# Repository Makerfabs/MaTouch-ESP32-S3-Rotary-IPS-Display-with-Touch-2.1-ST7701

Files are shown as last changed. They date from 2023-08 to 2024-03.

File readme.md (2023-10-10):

MaTouch ESP32-S3 Rotary IPS Display with Touch 2.1 ST7701

```c++
/*
Version:		V1.0
Author:		Vincent
Create Date:	2023/8/24
Note:

    2023/8/29   V1.1    Change out factory test program

*/
```

# Makerfabs

[Makerfabs home page](https://www.makerfabs.com/)

[Makerfabs Wiki](https://wiki.makerfabs.com/)

## Intruduce

Product Link:[]()

Wiki Link : []()

## Features

Specs:
- Controller: ESP32-S3
- Wireless: WiFi& Bluetooth 5.0
- Touch Panel Driver: CST826
- USB: USB Native, Type-C
- Power Supply: USB Type-C 5.0V(4.0V~5.25V)
- Button: Flash button and reset button
- Arduino support: Yes
- MicroPython support: Yes
- Operation temperature: -40℃ to +85℃

# Usage

## Libraries

Related library versions

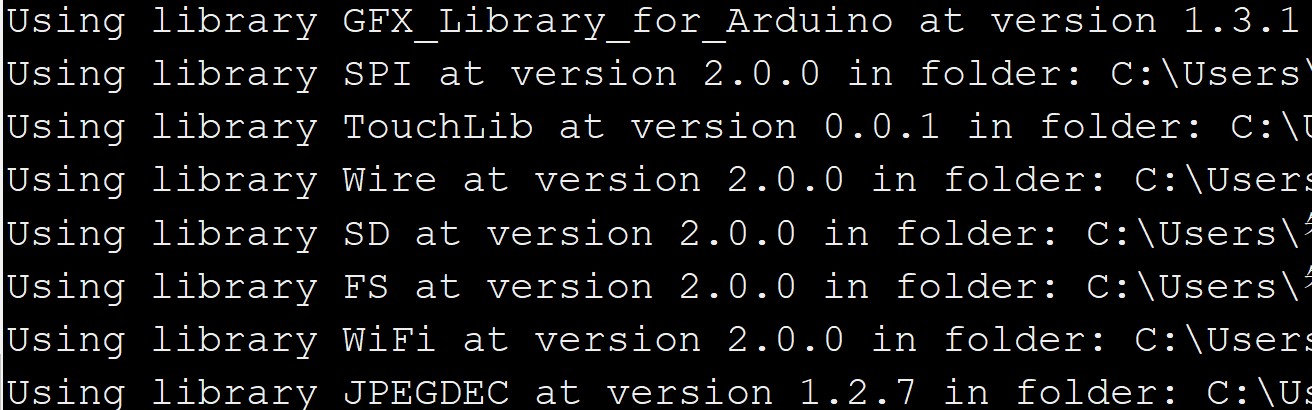
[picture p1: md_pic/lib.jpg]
library


- Use type-c use cable connect USB-TTL to PC.
- Select "ESP32-S3 DEV Module"
- Select PSRAM "OPI PSRAM"

"mf_Lvgl" library is modified from Lvgl library (version 8.3.2). 

Please unzip "lib/mf_Lvgl.zip","TouchLib" and copy to arduino library directory.

## Example

### fw_test

Old factory test program.
Test screen display and touch, as well as ring encoders and press switches.

### fw_test_v2

Factory test program.
Test screen display and touch, as well as ring encoders and press switches. After press screen, it will change different screen.

### fs_test

No SD card is required, files are stored in SPIFFS in Flash, and the display is switched by rotary encoder.

Need use arduino-esp32fs-plugin upload picture. And install JPEGDEC version 1.2.8

[arduino-esp32fs-plugin](https://github.com/me-no-dev/arduino-esp32fs-plugin)

### stepper_control

Control stepper motor rotation speed, rotation direction.

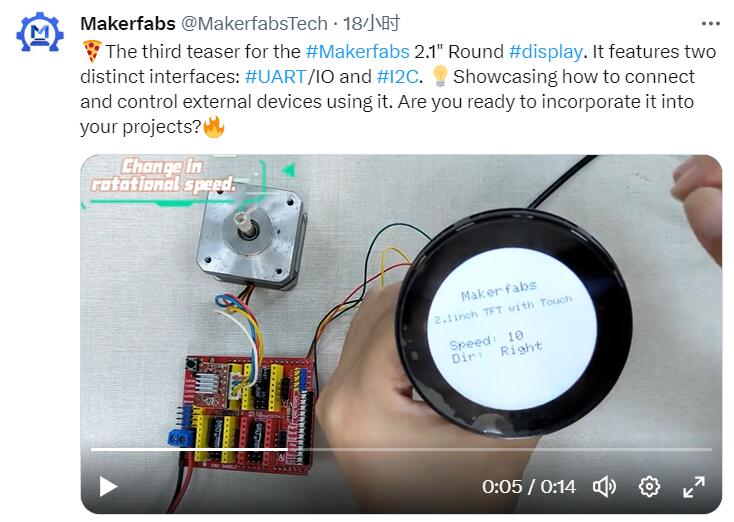
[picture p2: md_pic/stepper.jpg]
stepper


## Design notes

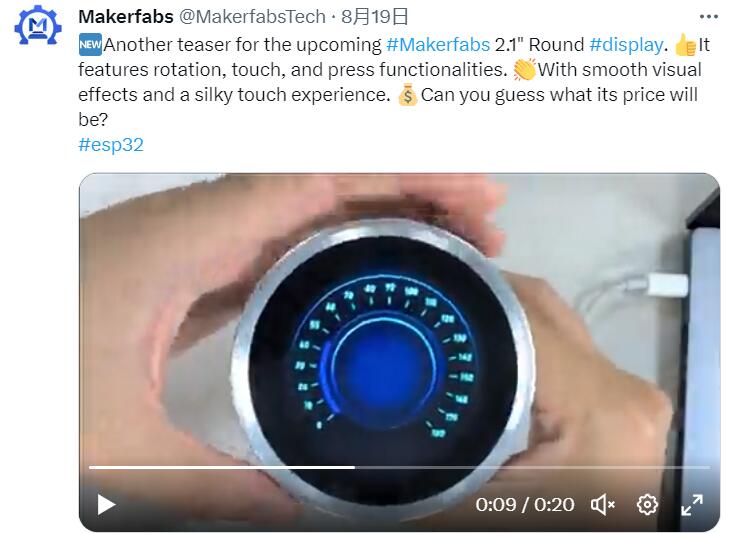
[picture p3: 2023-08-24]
md_pic/lvgl.jpg

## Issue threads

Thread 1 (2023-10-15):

No more compatible with GFX lib Version: 1.3.8, 1.3.7, 1.3.6, 1.3.5, 1.3.4, 1.3.3, 1.3.2.

Uspizig, 2023-10-15:
Compilation crashes on this one in the example with the GFX lib versions  1.3.8, 1.3.7, 1.3.6, 1.3.5, 1.3.4, 1.3.3, 1.3.2.
Works on 1.3.1. Please make it availible as well on newer GFX lib versions

Arduino_ESP32RGBPanel *bus = new Arduino_ESP32RGBPanel(
    1 /* CS */, 46 /* SCK */, 0 /* SDA */,
    2 /* DE */, 42 /* VSYNC */, 3 /* HSYNC */, 45 /* PCLK */,
    11 /* R0 */, 15 /* R1 */, 12 /* R2 */, 16 /* R3 */, 21 /* R4 */,
    39 /* G0/P22 */, 7 /* G1/P23 */, 47 /* G2/P24 */, 8 /* G3/P25 */, 48 /* G4/P26 */, 9 /* G5 */,
    4 /* B0 */, 41 /* B1 */, 5 /* B2 */, 40 /* B3 */, 6 /* B4 */
);

C:\Users\User\Downloads\MaTouch-ESP32-S3-Rotary-IPS-Display-with-Touch-2.1-ST7701-main\MaTouch-ESP32-S3-Rotary-IPS-Display-with-Touch-2.1-ST7701-main\example\fs_test\fs_test.ino:33:1: error: no matching function for call to 'Arduino_ESP32RGBPanel::Arduino_ESP32RGBPanel(int, int, int, int, int, int, int, int, int, int, int, int, int, int, int, int, int, int, int, int, int, int, int)'
 );
 ^
In file included from c:\Users\User\Documents\Arduino\libraries\GFX_Library_for_Arduino\src/Arduino_GFX_Library.h:15,
                 from C:\Users\User\Downloads\MaTouch-ESP32-S3-Rotary-IPS-Display-with-Touch-2.1-ST7701-main\MaTouch-ESP32-S3-Rotary-IPS-Display-with-Touch-2.1-ST7701-main\example\fs_test\fs_test.ino:1:
c:\Users\User\Documents\Arduino\libraries\GFX_Library_for_Arduino\src/databus/Arduino_ESP32RGBPanel.h:59:3: note: candidate: 'Arduino_ESP32RGBPanel::Arduino_ESP32RGBPanel(int8_t, int8_t, int8_t, int8_t, int8_t, int8_t, int8_t, int8_t, int8_t, int8_t, int8_t, int8_t, int8_t, int8_t, int8_t, int8_t, int8_t, int8_t, int8_t, int8_t, uint16_t, uint16_t, uint16_t, uint16_t, uint16_t, uint16_t, uint16_t, uint16_t, uint16_t, int32_t, bool, uint16_t, uint16_t)'
   Arduino_ESP32RGBPanel(
   ^~~~~~~~~~~~~~~~~~~~~
c:\Users\User\Documents\Arduino\libraries\GFX_Library_for_Arduino\src/databus/Arduino_ESP32RGBPanel.h:59:3: note:   candidate expects 33 arguments, 23 provided
c:\Users\User\Documents\Arduino\libraries\GFX_Library_for_Arduino\src/databus/Arduino_ESP32RGBPanel.h:56:7: note: candidate: 'constexpr Arduino_ESP32RGBPanel::Arduino_ESP32RGBPanel(const Arduino_ESP32RGBPanel&)'
 class Arduino_ESP32RGBPanel
       ^~~~~~~~~~~~~~~~~~~~~
c:\Users\User\Documents\Arduino\libraries\GFX_Library_for_Arduino\src/databus/Arduino_ESP32RGBPanel.h:56:7: note:   candidate expects 1 argument, 23 provided
c:\Users\User\Documents\Arduino\libraries\GFX_Library_for_Arduino\src/databus/Arduino_ESP32RGBPanel.h:56:7: note: candidate: 'constexpr Arduino_ESP32RGBPanel::Arduino_ESP32RGBPanel(Arduino_ESP32RGBPanel&&)'
c:\Users\User\Documents\Arduino\libraries\GFX_Library_for_Arduino\src/databus/Arduino_ESP32RGBPanel.h:56:7: note:   candidate expects 1 argument, 23 provided
C:\Users\User\Downloads\MaTouch-ESP32-S3-Rotary-IPS-Display-with-Touch-2.1-ST7701-main\MaTouch-ESP32-S3-Rotary-IPS-Display-with-Touch-2.1-ST7701-main\example\fs_test\fs_test.ino:36:1: error: 'Arduino_ST7701_RGBPanel' does not name a type; did you mean 'Arduino_ESP32RGBPanel'?
 Arduino_ST7701_RGBPanel *gfx = new Arduino_ST7701_RGBPanel(
 ^~~~~~~~~~~~~~~~~~~~~~~
 Arduino_ESP32RGBPanel
C:\Users\User\Downloads\MaTouch-ESP32-S3-Rotary-IPS-Display-with-Touch-2.1-ST7701-main\MaTouch-ESP32-S3-Rotary-IPS-Display-with-Touch-2.1-ST7701-main\example\fs_test\fs_test.ino: In function 'int jpegDrawCallback(JPEGDRAW*)':
C:\Users\User\Downloads\MaTouch-ESP32-S3-Rotary-IPS-Display-with-Touch-2.1-ST7701-main\MaTouch-ESP32-S3-Rotary-IPS-Display-with-Touch-2.1-ST7701-main\example\fs_test\fs_test.ino:50:5: error: 'gfx' was not declared in this scope
     gfx->draw16bitBeRGBBitmap(pDraw->x, pDraw->y, pDraw->pPixels, pDraw->iWidth, pDraw->iHeight);
     ^~~
C:\Users\User\Downloads\MaTouch-ESP32-S3-Rotary-IPS-Display-with-Touch-2.1-ST7701-main\MaTouch-ESP32-S3-Rotary-IPS-Display-with-Touch-2.1-ST7701-main\example\fs_test\fs_test.ino: In function 'void setup()':
C:\Users\User\Downloads\MaTouch-ESP32-S3-Rotary-IPS-Display-with-Touch-2.1-ST7701-main\MaTouch-ESP32-S3-Rotary-IPS-Display-with-Touch-2.1-ST7701-main\example\fs_test\fs_test.ino:60:5: error: 'gfx' was not declared in this scope
     gfx->begin();
     ^~~

exit status 1

Compilation error: no matching function for call to 'Arduino_ESP32RGBPanel::Arduino_ESP32RGBPanel(int, int, int, int, int, int, int, int, int, int, int, int, int, int, int, int, int, int, int, int, int, int, int)'

only works with GFX lib 1.3.1

Uspizig, 2023-10-16:
This might be a workaround. [Untested due to lack of Hardware]
At least it compiles:

#define I2C_SDA_PIN 17
#define I2C_SCL_PIN 18
#define DISPLAY_DC GFX_NOT_DEFINED
#define DISPLAY_CS 1
#define DISPLAY_SCK 46
#define DISPLAY_MOSI 0
#define DISPLAY_MISO GFX_NOT_DEFINED

#define DISPLAY_DE 2
#define DISPLAY_VSYNC 42
#define DISPLAY_HSYNC 3
#define DISPLAY_PCLK 45
#define DISPLAY_R0 11
#define DISPLAY_R1 15
#define DISPLAY_R2 12
#define DISPLAY_R3 16
#define DISPLAY_R4 21
#define DISPLAY_G0 39
#define DISPLAY_G1 7
#define DISPLAY_G2 47
#define DISPLAY_G3 8
#define DISPLAY_G4 48
#define DISPLAY_G5 9
#define DISPLAY_B0 4
#define DISPLAY_B1 41
#define DISPLAY_B2 5
#define DISPLAY_B3 40
#define DISPLAY_B4 6
#define DISPLAY_HSYNC_POL 1
#define DISPLAY_VSYNC_POL 1
#define DISPLAY_HSYNC_FRONT_PORCH 10
#define DISPLAY_VSYNC_FRONT_PORCH 10
#define DISPLAY_HSYNC_BACK_PORCH 50
#define DISPLAY_VSYNC_BACK_PORCH 20
#define DISPLAY_HSYNC_PULSE_WIDTH 8
#define DISPLAY_VSYNC_PULSE_WIDTH 8

Arduino_DataBus *bus = new Arduino_SWSPI(
    DISPLAY_DC /* DC */, DISPLAY_CS /* CS */,
    DISPLAY_SCK /* SCK */, DISPLAY_MOSI /* MOSI */, DISPLAY_MISO /* MISO */);

Arduino_ESP32RGBPanel *rgbpanel = new Arduino_ESP32RGBPanel(
    DISPLAY_DE, DISPLAY_VSYNC , DISPLAY_HSYNC, DISPLAY_PCLK,
    DISPLAY_R0, DISPLAY_R1, DISPLAY_R2, DISPLAY_R3, DISPLAY_R4,
    DISPLAY_G0, DISPLAY_G1, DISPLAY_G2, DISPLAY_G3, DISPLAY_G4, DISPLAY_G5,
    DISPLAY_B0, DISPLAY_B1, DISPLAY_B2, DISPLAY_B3, DISPLAY_B4,
    DISPLAY_HSYNC_POL, DISPLAY_HSYNC_FRONT_PORCH, DISPLAY_HSYNC_PULSE_WIDTH, DISPLAY_VSYNC_BACK_PORCH,
    DISPLAY_VSYNC_POL, DISPLAY_VSYNC_FRONT_PORCH, DISPLAY_VSYNC_PULSE_WIDTH, DISPLAY_VSYNC_BACK_PORCH);

Arduino_RGB_Display *gfx = new Arduino_RGB_Display(
    480 /* width */, 480 /* height */, rgbpanel, 0 /* rotation */, true /* auto_flush */,
    bus, GFX_NOT_DEFINED /* RST */, st7701_type5_init_operations, sizeof(st7701_type5_init_operations));

//Arduino_ESP32RGBPanel *bus = new Arduino_ESP32RGBPanel(
//    1 /* CS */, 46 /* SCK */, 0 /* SDA */,
//    2 /* DE */, 42 /* VSYNC */, 3 /* HSYNC */, 45 /* PCLK */,
//    11 /* R0 */, 15 /* R1 */, 12 /* R2 */, 16 /* R3 */, 21 /* R4 */,
//    39 /* G0/P22 */, 7 /* G1/P23 */, 47 /* G2/P24 */, 8 /* G3/P25 */, 48 /* G4/P26 */, 9 /* G5 */,
//    4 /* B0 */, 41 /* B1 */, 5 /* B2 */, 40 /* B3 */, 6 /* B4 */
//);

// Uncomment for 2.1" round display
//Arduino_ST7701_RGBPanel *gfx = new Arduino_ST7701_RGBPanel(
//    bus, GFX_NOT_DEFINED /* RST */, 0 /* rotation */,
//    false /* IPS */, 480 /* width */, 480 /* height */,
//    st7701_type5_init_operations, sizeof(st7701_type5_init_operations),
//    true /* BGR */,
//    10 /* hsync_front_porch */, 8 /* hsync_pulse_width */, 50 /* hsync_back_porch */,
//    10 /* vsync_front_porch */, 8 /* vsync_pulse_width */, 20 /* vsync_back_porch */);

wegunterjr, 2023-10-29:
getting similar results. I am unable to compile any of the examples.   Any suggestions?

Uspizig, 2023-10-29:
did you check the above rework/fix and replaxced the part?

wegunterjr, 2023-10-29:
Yes. I tried your suggestion above and there are a few other matouch products that have similar suggestions for the library difference.  It seems to get past the gfx part once I do and then I get the overload errors.

Maybe I have Arduino settings wrong?
I am also trying this in vscode which is my preference IDE.

wegunterjr, 2023-10-30:
This was my mistake - my error was different because I was using a different version of Arduino IDE. The Wiki suggested 1.8 and I was using the latest - I was able to get the included examples working. I haven't progressed to this version of the driver yet, but I will try your suggestion above when I do.

Uspizig, 2023-10-30:
I am using the latest Arduino IDE 2.2.1 ... works... I think your issue is different:

Could you try out the code below:

[fs_test.txt](https://github.com/Makerfabs/MaTouch-ESP32-S3-Rotary-IPS-Display-with-Touch-2.1-ST7701/files/13209271/fs_test.txt)

wegunterjr, 2023-10-30:
I am not sure what my issue is - I am getting

`WARNING: library Audio claims to run on sam architecture(s) and may be incompatible with your current board which runs on esp32 architecture(s).`

`error: 'Dacc' does not name a type
  Dacc *dac;`

wegunterjr, 2023-10-31:
I switched the project over to vscode and I got the same error you posted above using 1.3.8.  I used your suggestion above and am able to compile and it runs on the HW.

Closed 2023-10-30.

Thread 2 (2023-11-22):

FW Sketch and Arduino Settings Incompatible

SuperJonotron, 2023-11-22:
Following the wiki for setup (https://wiki.makerfabs.com/MaTouch_ESP32_S3_2.1_Rotary_TFT_with_Touch.html) you are immediately hit with the error indicated at the bottom:

> I get the failed message from serial after I uploaded the code to the board: no mem for frame buffer ESP_ERROR_CHECK failed: esp_err_t 0x101 (ESP_ERR_NO_MEM) at 0x4037af3c, the screen shows nothing. What's wrong? A3： There is no enough memory, you must select PSRAM "OPIPSRAM": in Arduino IDE. As the same, 16MB Flash and 3MB APP/9.9MB FATFS are also recommannded for huge application.

Presumably the default fw_test_v2 is installed on the device I received and worked on arrival.  In an attempt to make sure I could upload and understand the basics of the sketch, I followed the examples and uploaded the sketch only to be met with that error streaming.  So if this is the true way to set it up, and it fails, then either the sketch is invalid or the settings are incorrect in the guide.

slowriding, 2023-12-09:
I'm using Arduino IDE 2.2.1 following the directions and got fw_test_v2 to compile, load and run.
Because the modified libraries are not forked or updated for this device I started from a fresh IDE install and am afraid to load any other projects or extra libraries.  I guess I should run it in a container so I don't break it now that it is compiling.

I still have not got the UI example to compile though.

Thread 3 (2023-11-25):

Platform.io Partition Table for max use of 16MB Flash

PlastiBots, 2023-11-25:
Having difficulty with partition tables to get max use of the 16MB flash.  I have a number of large images that I need to upload. The only option that works is board_build.partitions = default_8MB.csv, but this is too small and does not use the 16MB available.  I had a custom partition csv file that works with my LilyGo T-RGB (same board and specs), but it does not work with this unit. All other options below (commented out) build and upload, but case the ESP to crash on boot.  Has anyone had any luck with getting the right partition table for this board?

`[env:NeoLumn8_MaTouch_V3]`
platform = espressif32
board = esp32-s3-devkitc-1
framework = arduino
build_flags =
    -DARDUINO_USB_MODE=1
	-DARDUINO_USB_CDC_ON_BOOT=1
	-DBOARD_HAS_PSRAM
board_build.arduino.memory_type = qio_opi
board_build.f_flash = 80000000L
board_build.flash_mode = qio
; partion options: https://github.com/espressif/arduino-esp32/tree/master/tools/partitions
board_build.partitions = default_8MB.csv
;board_build.partitions = app3M_fat9M_16MB.csv   ;FAIL
;board_build.partitions = default_16MB.csv  ;FAIL
;board_build.partitions = large_spiffs_16MB.csv ;FAIL
upload_flags = --no-stub
monitor_speed = 115200
`

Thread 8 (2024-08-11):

How to get word a Gps-module on MaTouch-ESP32S§-Rotary?

vintagecardriver, 2024-08-11:
Hi,

has anyone any recommendation how to get work a GPS-module like for example a Neo-6M on the MaTouch-ESP32S§-Rotary, please?
I've tried many many hours, but didn't have any success.

cnjboards, 2024-11-03:
I have built a daughter card which remaps gpio 43/44 J2 to a Canbus transceiver and had no issues. Also you should be able to connect another I2C device to the bus. The I2C bus is designed to have multiple devices on the bus. You just need to make sure the address on the bus is unique.

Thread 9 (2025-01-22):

Wrong Hardware Files

SkydiveH, 2025-01-22:
I tried to install a display without Touch. For this I checked the bus pinout of the GFX Library and compared it to the schematic and found, that the schematic is obsolete. Does somebody has a valid one. The schematic is 1.1.  If somebody also has the datasheet of the display then I#m able to sort it out.

Here is the schematic part of the IPS display.
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

and that is the pin definition from the GFX Lib. It is working with the pin assignment of the Lib.

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

SkydiveH

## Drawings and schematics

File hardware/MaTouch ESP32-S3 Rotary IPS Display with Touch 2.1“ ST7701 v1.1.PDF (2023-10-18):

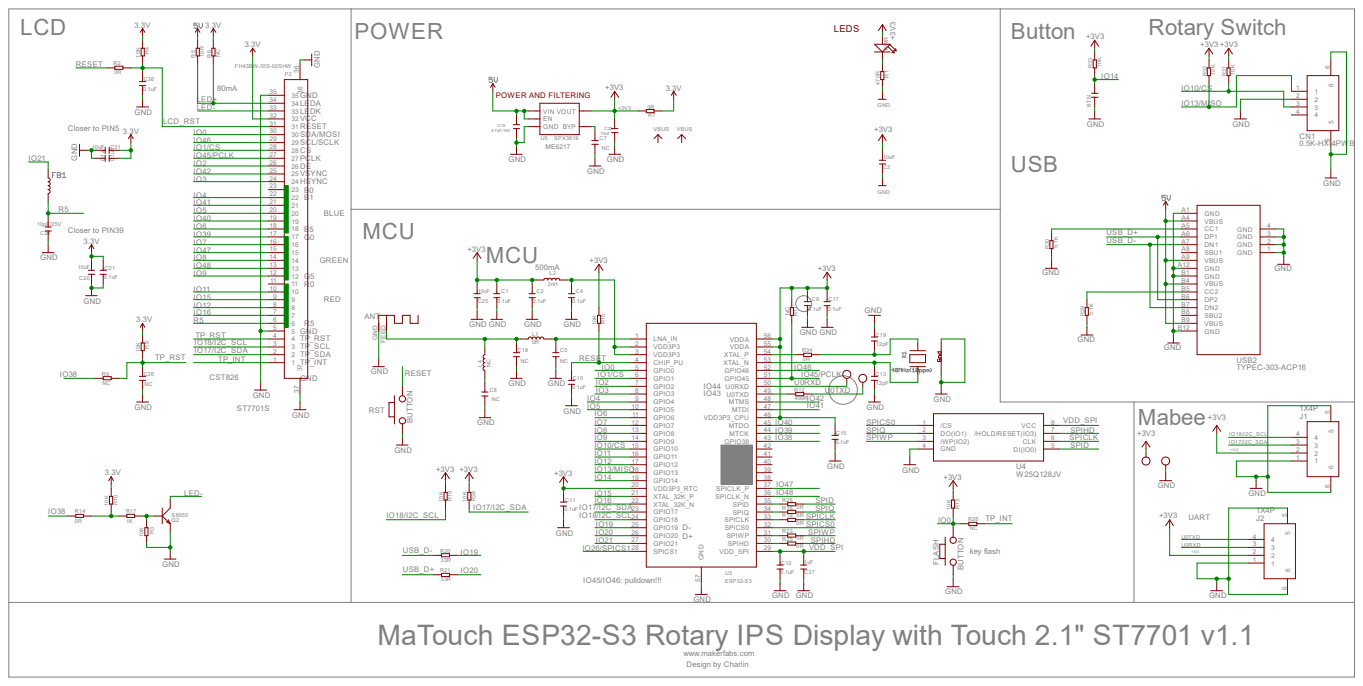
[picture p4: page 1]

IO17/I2C_SDA
key flash MaTouch ESP32-S3 Rotary IPS Display with Touch 2.1" ST7701 v1.1

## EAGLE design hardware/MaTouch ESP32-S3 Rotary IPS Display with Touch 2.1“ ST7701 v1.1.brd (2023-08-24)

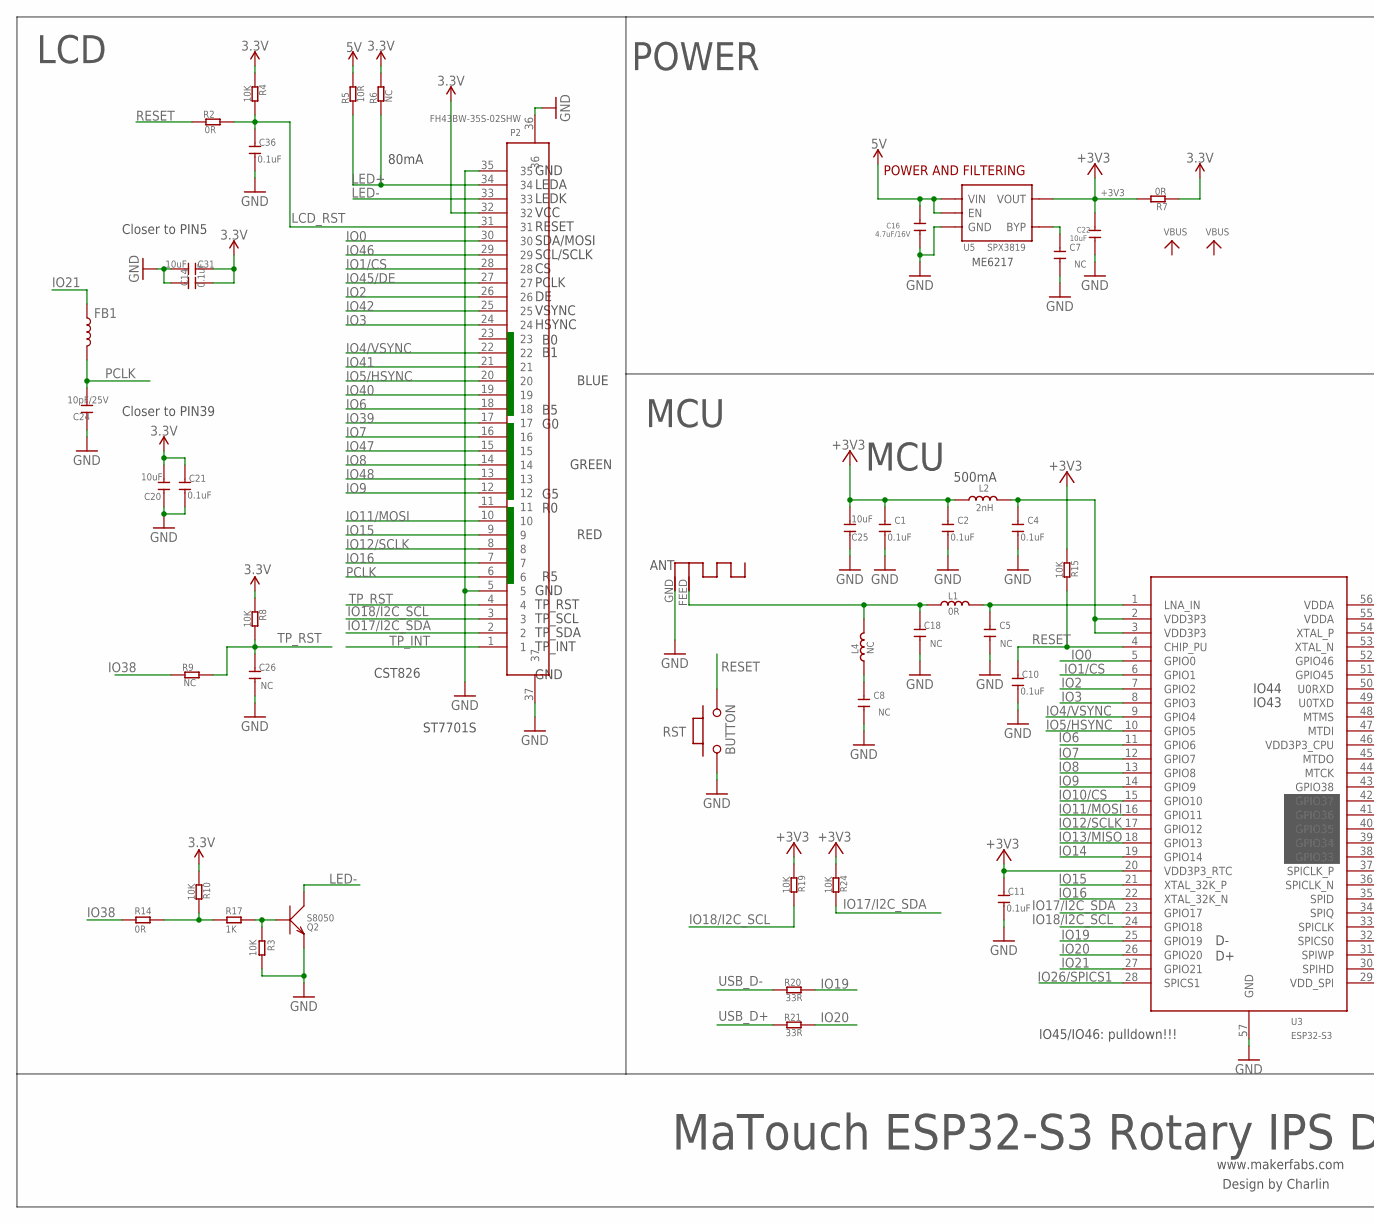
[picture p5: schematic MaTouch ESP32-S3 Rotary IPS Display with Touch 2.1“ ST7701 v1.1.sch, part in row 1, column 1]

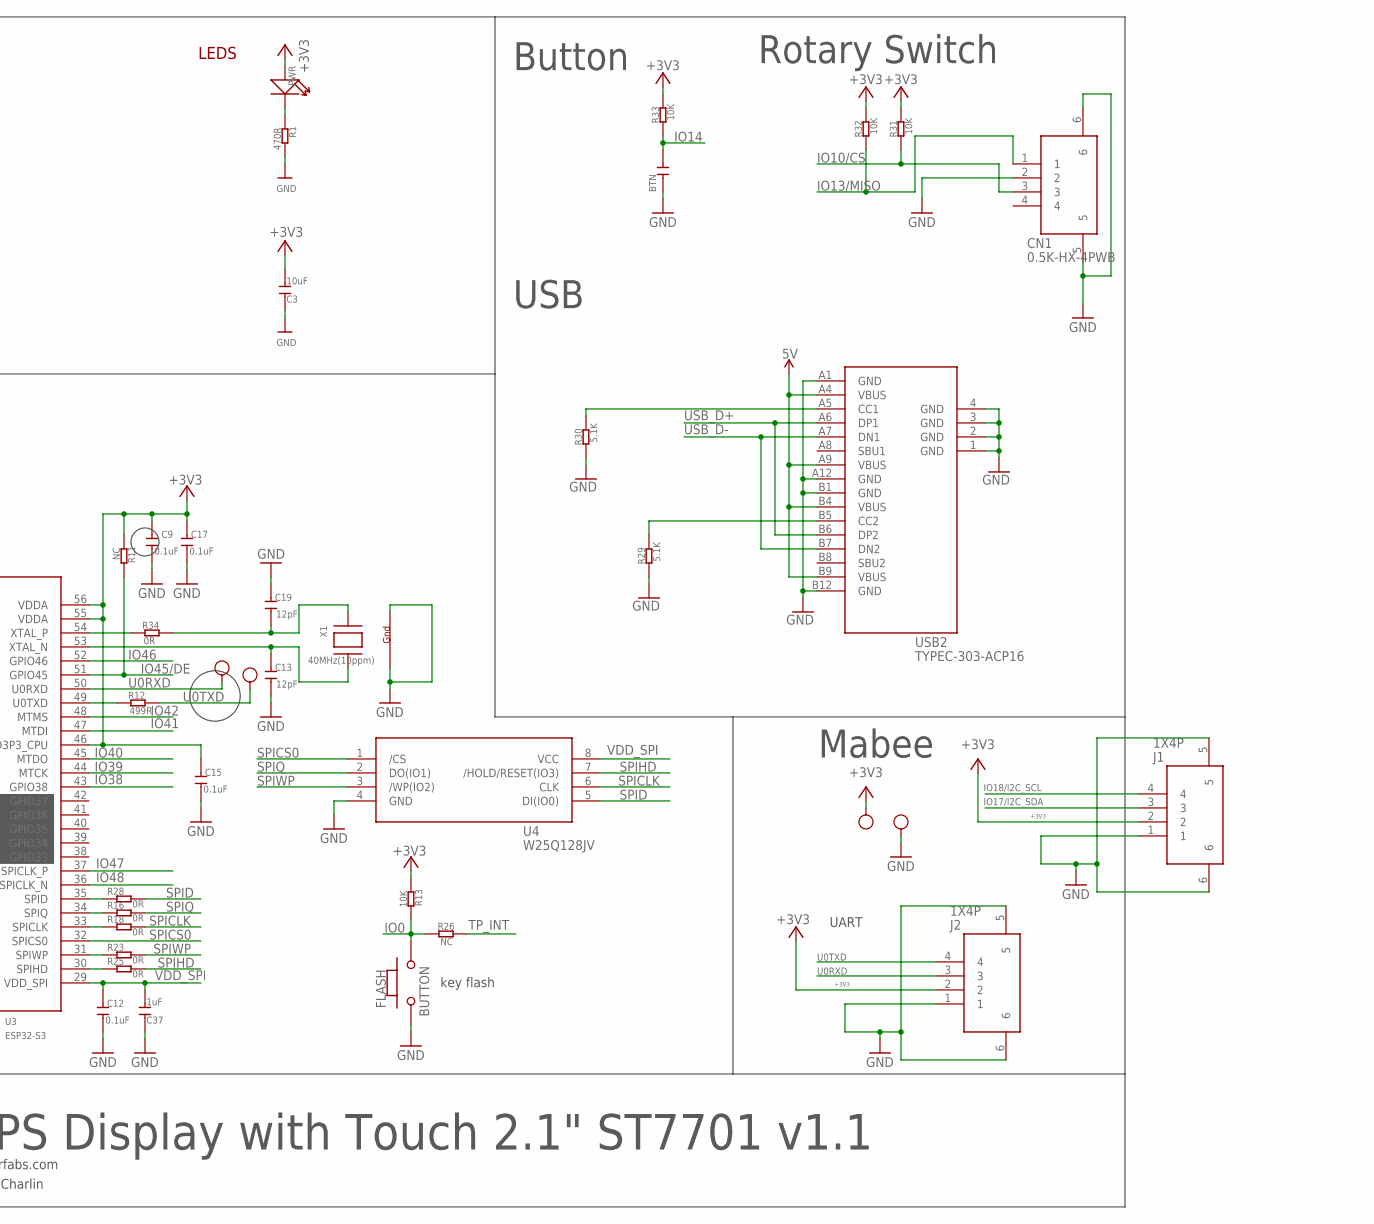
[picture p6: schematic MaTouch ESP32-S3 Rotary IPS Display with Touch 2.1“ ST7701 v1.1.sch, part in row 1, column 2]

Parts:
3V3: TEST-POINT'4545'; TP-D45MIL; PARTNO DNP
ANT1: ANTENNA; RN-ANT
BTN: C'5.08'; CERAMIC-5.08
C1, C2, C4, C9, C10, C11, C12, C14, C15, C17, C21, C36: 0.1uF; DISCRETE_C0402
C3, C20, C25, C31: 10uF; DISCRETE_C0603
C5, C7, C8, C18, C26: NC; DISCRETE_C0402
C13, C19: 12pF; DISCRETE_C0402
C16: 4.7uF/16V; 0603
C22: 10uF; 0603
C24: 10pF/25V; DISCRETE_C0402
C37: 1uF; DISCRETE_C0603
CN1: 0.5K-HX-4PWB
FB1: INDUCTORFB-30OHM; 0603
FLASH: BUTTON; 157SW
GND: TEST-POINT'4545'; TP-D45MIL; PARTNO DNP
J1, J2: 1X4P; 1X4P-SMT1.25MM
L1: 0R; DISCRETE_L0402
L2: 2nH; DISCRETE_L0603
L4: NC; DISCRETE_L0402
P2: FH43BW-35S-02SHW; 1*35P-SMT0.4MM
PWR: DISCRETE_LED0603; DISCRETE_LED-0603
Q2: S8050; SOT23
R1: 470R; DISCRETE_R0402
R2, R7, R14, R16, R18, R23, R25, R28, R34: 0R; DISCRETE_R0402
R3, R4, R8, R10, R13, R15, R19, R24, R31, R32, R33: 10K; DISCRETE_R0402
R5: 10R; DISCRETE_R0402
R6, R9, R11, R26: NC; DISCRETE_R0402
R12: 499R; DISCRETE_R0402
R17: 1K; DISCRETE_R0402
R20, R21: 33R; DISCRETE_R0402
R29, R30: 5.1K; DISCRETE_R0402
RST: BUTTON; 157SW
RX: TEST-POINT'4545'; TP-D45MIL; PARTNO DNP
TX: TEST-POINT'4545'; TP-D45MIL; PARTNO DNP
U3: ESP32-S3; QFN56-7*7MM
U4: W25Q128JV; SOIC-8-208MIL
U5: SPX3819; SOT23-5
USB2: TYPEC-303-ACP16; TYPEC-303-SMD16
X1: 40MHz(10ppm); NX3225

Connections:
3.3V: C14.1, C20.2, C21.2, C31.1, P2.32, R4.2, R6.1, R7.2, R8.2, R10.2
5V: C16.1, R5.1, U5.1 (VIN), U5.3 (EN), USB2.A4 (VBUS), USB2.A9 (VBUS), USB2.B4 (VBUS), USB2.B9 (VBUS)
+3V3: 3V3.T, C1.2, C2.2, C3.2, C9.2, C11.2, C15.2, C17.2, C22.1, C25.2, J1.2, J2.2, L2.1, PWR.+, R7.1, R11.2, R13.2, R15.2, R19.2, R24.2, R31.1, R32.1, R33.1, U3.20 (VDD3P3_RTC), U3.46 (VDD3P3_CPU), U3.55 (VDDA), U3.56 (VDDA), U5.5 (VOUT)
GND: ANT1.GND, BTN.1, C1.1, C2.1, C3.1, C4.1, C5.1, C7.1, C8.1, C9.1, C10.1, C11.1, C12.1, C13.1, C14.2, C15.1, C16.2, C17.1, C18.1, C19.2, C20.1, C21.1, C22.2, C24.2, C25.1, C26.1, C31.2, C36.1, C37.1, CN1.2, CN1.5, CN1.6, FLASH.1, GND.T, J1.1, J1.5, J1.6, J2.1, J2.5, J2.6, P2.5, P2.35, P2.36, P2.37, Q2.2 (E), R1.1, R3.1, R29.2, R30.2, RST.1, U3.57 (GND), U4.4 (GND), U5.2 (GND), USB2.1 (GND), USB2.2 (GND), USB2.3 (GND), USB2.4 (GND), USB2.A1 (GND), USB2.A12 (GND), USB2.B1 (GND), USB2.B12 (GND), X1.2 (G2), X1.4 (G1)
IO0: FLASH.2, P2.30, R13.1, R26.2, U3.5 (GPIO0)
IO1/CS: P2.28, U3.6 (GPIO1)
IO2: P2.26, U3.7 (GPIO2)
IO3: P2.24, U3.8 (GPIO3)
IO4/VSYNC: P2.22, U3.9 (GPIO4)
IO5/HSYNC: P2.20, U3.10 (GPIO5)
IO6: P2.18, U3.11 (GPIO6)
IO7: P2.16, U3.12 (GPIO7)
IO8: P2.14, U3.13 (GPIO8)
IO9: P2.12, U3.14 (GPIO9)
IO10/CS: CN1.3, R31.2, U3.15 (GPIO10)
IO11/MOSI: P2.10, U3.16 (GPIO11)
IO12/SCLK: P2.8, U3.17 (GPIO12)
IO13/MISO: CN1.1, R32.2, U3.18 (GPIO13)
IO14: BTN.2, R33.2, U3.19 (GPIO14)
IO15: P2.9, U3.21 (XTAL_32K_P)
IO16: P2.7, U3.22 (XTAL_32K_N)
IO17/I2C_SDA: J1.3, P2.2, R24.1, U3.23 (GPIO17)
IO18/I2C_SCL: J1.4, P2.3, R19.1, U3.24 (GPIO18)
IO19: R20.1, U3.25 (GPIO19)
IO20: R21.1, U3.26 (GPIO20)
IO21: FB1.1, U3.27 (GPIO21)
IO26/SPICS1: U3.28 (SPICS1)
IO38: R9.2, R14.2, U3.43 (GPIO38)
IO39: P2.17, U3.44 (MTCK)
IO40: P2.19, U3.45 (MTDO)
IO41: P2.21, U3.47 (MTDI)
IO42: P2.25, U3.48 (MTMS)
IO45/DE: P2.27, R11.1, U3.51 (GPIO45)
IO46: P2.29, U3.52 (GPIO46)
IO47: P2.15, U3.37 (SPICLK_P)
IO48: P2.13, U3.36 (SPICLK_N)
LCD_RST: C36.2, P2.31, R2.1, R4.1
LED+: P2.34, R5.2, R6.2
LED-: P2.33, Q2.3 (C)
unnamed: ANT1.FEED, C18.2, L1.1, L4.2
unnamed: C5.2, L1.2, U3.1 (LNA_IN)
unnamed: R28.2, U3.35 (SPID)
unnamed: C8.2, L4.1
unnamed: R10.1, R14.1, R17.2
unnamed: PWR.-, R1.2
unnamed: Q2.1 (B), R3.2, R17.1
unnamed: R30.1, USB2.A5 (CC1)
unnamed: R29.1, USB2.B5 (CC2)
unnamed: C4.2, L2.2, U3.2 (VDD3P3), U3.3 (VDD3P3)
unnamed: R16.2, U3.34 (SPIQ)
unnamed: R34.2, U3.54 (XTAL_P)
unnamed: R18.2, U3.33 (SPICLK)
unnamed: R23.2, U3.31 (SPIWP)
unnamed: R25.2, U3.30 (SPIHD)
unnamed: R12.2, U3.49 (U0TXD)
unnamed: C13.2, U3.53 (XTAL_N), X1.3 (X2)
unnamed: C19.1, R34.1, X1.1 (X1)
unnamed: C7.2, U5.4 (BYP)
PCLK: C24.1, FB1.2, P2.6
RESET: C10.2, R2.2, R15.1, RST.2, U3.4 (CHIP_PU)
SPICLK: R18.1, U4.6 (CLK)
SPICS0: U3.32 (SPICS0), U4.1 (/CS)
SPID: R28.1, U4.5 (DI(IO0))
SPIHD: R25.1, U4.7 (/HOLD/RESET(IO3))
SPIQ: R16.1, U4.2 (DO(IO1))
SPIWP: R23.1, U4.3 (/WP(IO2))
TP_INT: P2.1, R26.1
TP_RST: C26.2, P2.4, R8.1, R9.1
U0RXD: J2.3, RX.T, U3.50 (U0RXD)
U0TXD: J2.4, R12.1, TX.T
USB_D+: R21.2, USB2.A6 (DP1), USB2.B6 (DP2)
USB_D-: R20.2, USB2.A7 (DN1), USB2.B7 (DN2)
VDD_SPI: C12.2, C37.2, U3.29 (VDD_SPI), U4.8 (VCC)

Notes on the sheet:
www.makerfabs.com
Design by Charlin
LEDS
POWER AND FILTERING
key flash
MaTouch ESP32-S3 Rotary IPS Display with Touch 2.1" ST7701 v1.1
POWER
CST826
Mabee
LCD
MCU
Closer to PIN5
LEDA
LEDK
VCC
TP_INT
RESET
SDA/MOSI
SCL/SCLK
PCLK
VSYNC
HSYNC
TP_SDA
TP_SCL
TP_RST
ST7701S
GND
BLUE
GREEN
RED
Closer to PIN39
ME6217
500mA
IO45/IO46: pulldown!!!
IO43
IO44
80mA
ANT
USB
Button

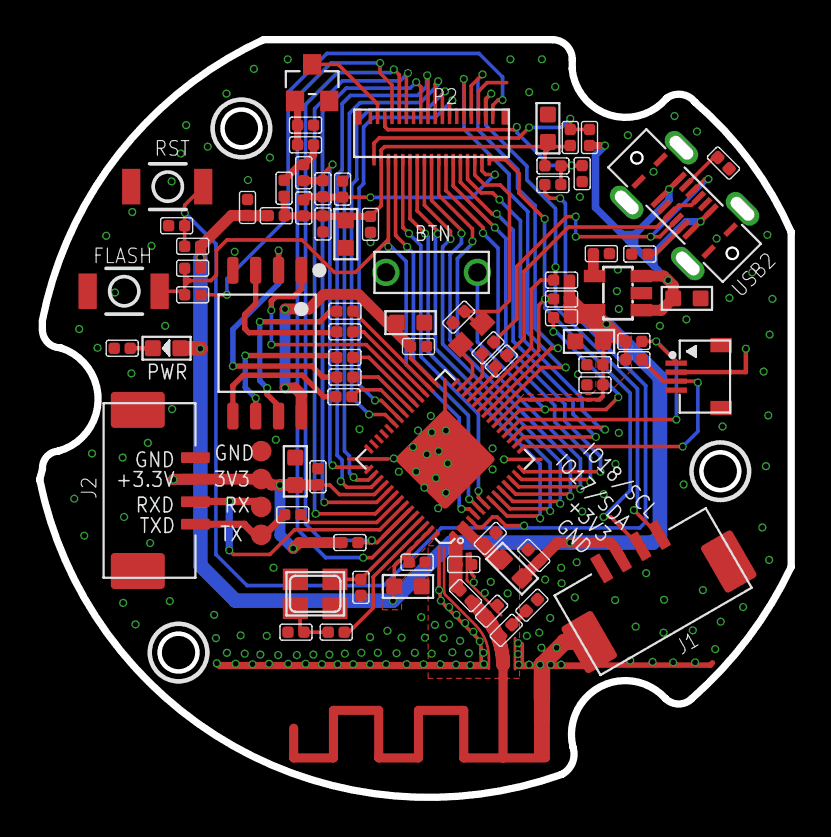
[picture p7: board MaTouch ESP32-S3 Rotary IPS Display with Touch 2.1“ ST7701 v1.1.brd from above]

Board: 2 copper layers, 41.8 x 42.1 mm, 83 parts (1 on the bottom side), 72 nets.

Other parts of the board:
U$1: MAKERFABS_0.3

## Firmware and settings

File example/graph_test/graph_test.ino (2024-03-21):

#include <Arduino_GFX_Library.h>

#define TFT_BLK 38

Arduino_ESP32RGBPanel *bus = new Arduino_ESP32RGBPanel(
    1 /* CS */, 46 /* SCK */, 0 /* SDA */,
    2 /* DE */, 42 /* VSYNC */, 3 /* HSYNC */, 45 /* PCLK */,
    11 /* R0 */, 15 /* R1 */, 12 /* R2 */, 16 /* R3 */, 21 /* R4 */,
    39 /* G0/P22 */, 7 /* G1/P23 */, 47 /* G2/P24 */, 8 /* G3/P25 */, 48 /* G4/P26 */, 9 /* G5 */,
    4 /* B0 */, 41 /* B1 */, 5 /* B2 */, 40 /* B3 */, 6 /* B4 */
);

// Uncomment for 2.1" round display
Arduino_ST7701_RGBPanel *gfx = new Arduino_ST7701_RGBPanel(
    bus, GFX_NOT_DEFINED /* RST */, 0 /* rotation */,
    false /* IPS */, 480 /* width */, 480 /* height */,
    st7701_type5_init_operations, sizeof(st7701_type5_init_operations),
    true /* BGR */,
    10 /* hsync_front_porch */, 8 /* hsync_pulse_width */, 50 /* hsync_back_porch */,
    10 /* vsync_front_porch */, 8 /* vsync_pulse_width */, 20 /* vsync_back_porch */);

int32_t w, h, n, n1, cx, cy, cx1, cy1, cn, cn1;
uint8_t tsa, tsb, tsc, ds;

void setup()
{
    pinMode(TFT_BLK, OUTPUT);
    digitalWrite(TFT_BLK, HIGH);

    Serial.begin(115200);
    // Serial.setDebugOutput(true);
    // while(!Serial);
    Serial.println("Arduino_GFX library Test!");

    gfx->begin();
    // gfx->begin(80000000); /* specify data bus speed */

    w = gfx->width();
    h = gfx->height();
    n = min(w, h);
    n1 = n - 1;
    cx = w / 2;
    cy = h / 2;
    cx1 = cx - 1;
    cy1 = cy - 1;
    cn = min(cx1, cy1);
    cn1 = cn - 1;
    tsa = ((w <= 176) || (h <= 160)) ? 1 : (((w <= 240) || (h <= 240)) ? 2 : 3); // text size A
    tsb = ((w <= 272) || (h <= 220)) ? 1 : 2;                                    // text size B
    tsc = ((w <= 220) || (h <= 220)) ? 1 : 2;                                    // text size C
    ds = (w <= 160) ? 9 : 12;                                                    // digit size

#ifdef GFX_BL
    pinMode(GFX_BL, OUTPUT);
    digitalWrite(GFX_BL, HIGH);
#endif
}

static inline uint32_t micros_start() __attribute__((always_inline));
static inline uint32_t micros_start()
{
    uint8_t oms = millis();
    while ((uint8_t)millis() == oms)
        ;
    return micros();
}

void loop(void)
{
    Serial.println(F("Benchmark\tmicro-secs"));

    int32_t usecFillScreen = testFillScreen();
    serialOut(F("Screen fill\t"), usecFillScreen, 100, true);

    int32_t usecText = testText();
    serialOut(F("Text\t"), usecText, 3000, true);

    int32_t usecPixels = testPixels();
    serialOut(F("Pixels\t"), usecPixels, 100, true);

    int32_t usecLines = testLines();
    serialOut(F("Lines\t"), usecLines, 100, true);

    int32_t usecFastLines = testFastLines();
    serialOut(F("Horiz/Vert Lines\t"), usecFastLines, 100, true);

    int32_t usecFilledRects = testFilledRects();
    serialOut(F("Rectangles (filled)\t"), usecFilledRects, 100, false);

    int32_t usecRects = testRects();
    serialOut(F("Rectangles (outline)\t"), usecRects, 100, true);

    int32_t usecFilledTrangles = testFilledTriangles();
    serialOut(F("Triangles (filled)\t"), usecFilledTrangles, 100, false);

    int32_t usecTriangles = testTriangles();
    serialOut(F("Triangles (outline)\t"), usecTriangles, 100, true);

    int32_t usecFilledCircles = testFilledCircles(10);
    serialOut(F("Circles (filled)\t"), usecFilledCircles, 100, false);

    int32_t usecCircles = testCircles(10);
    serialOut(F("Circles (outline)\t"), usecCircles, 100, true);

    int32_t usecFilledArcs = testFillArcs();
    serialOut(F("Arcs (filled)\t"), usecFilledArcs, 100, false);

    int32_t usecArcs = testArcs();
    serialOut(F("Arcs (outline)\t"), usecArcs, 100, true);

    int32_t usecFilledRoundRects = testFilledRoundRects();
    serialOut(F("Rounded rects (filled)\t"), usecFilledRoundRects, 100, false);

    int32_t usecRoundRects = testRoundRects();
    serialOut(F("Rounded rects (outline)\t"), usecRoundRects, 100, true);

#ifdef CANVAS
    uint32_t start = micros_start();
    gfx->flush();
    int32_t usecFlush = micros() - start;
    serialOut(F("flush (Canvas only)\t"), usecFlush, 0, false);
#endif

    Serial.println(F("Done!"));

    uint16_t c = 4;
    int8_t d = 1;
    for (int32_t i = 0; i < h; i++)
    {
        gfx->drawFastHLine(0, i, w, c);
        c += d;
        if (c <= 4 || c >= 11)
        {
            d = -d;
        }
    }

    gfx->setCursor(0, 0);

    gfx->setTextSize(tsa);
    gfx->setTextColor(MAGENTA);
    gfx->println(F("Arduino GFX PDQ"));

    if (h > w)
    {
        gfx->setTextSize(tsb);
        gfx->setTextColor(GREEN);
        gfx->print(F("\nBenchmark "));
        gfx->setTextSize(tsc);
        if (ds == 12)
        {
            gfx->print(F("   "));
        }
        gfx->println(F("micro-secs"));
    }

    printnice(F("Screen fill "), usecFillScreen);
    printnice(F("Text        "), usecText);
    printnice(F("Pixels      "), usecPixels);
    printnice(F("Lines       "), usecLines);
    printnice(F("H/V Lines   "), usecFastLines);
    printnice(F("Rectangles F"), usecFilledRects);
    printnice(F("Rectangles  "), usecRects);
    printnice(F("Triangles F "), usecFilledTrangles);
    printnice(F("Triangles   "), usecTriangles);
    printnice(F("Circles F   "), usecFilledCircles);
    printnice(F("Circles     "), usecCircles);
    printnice(F("Arcs F      "), usecFilledArcs);
    printnice(F("Arcs        "), usecArcs);
    printnice(F("RoundRects F"), usecFilledRoundRects);
    printnice(F("RoundRects  "), usecRoundRects);

    if ((h > w) || (h > 240))
    {
        gfx->setTextSize(tsc);
        gfx->setTextColor(GREEN);
        gfx->print(F("\nBenchmark Complete!"));
    }

#ifdef CANVAS
    gfx->flush();
#endif

    delay(60 * 1000L);
}

void serialOut(const __FlashStringHelper *item, int32_t v, uint32_t d, bool clear)
{
#ifdef CANVAS
    gfx->flush();
#endif
    Serial.print(item);
    if (v < 0)
    {
        Serial.println(F("N/A"));
    }
    else
    {
        Serial.println(v);
    }
    delay(d);
    if (clear)
    {
        gfx->fillScreen(BLACK);
    }
}

void printnice(const __FlashStringHelper *item, long int v)
{
    gfx->setTextSize(tsb);
    gfx->setTextColor(CYAN);
    gfx->print(item);

    gfx->setTextSize(tsc);
    gfx->setTextColor(YELLOW);
    if (v < 0)
    {
        gfx->println(F("      N / A"));
    }
    else
    {
        char str[32] = {0};
#ifdef RTL8722DM
        sprintf(str, "%d", (int)v);
#else
        sprintf(str, "%ld", v);
#endif
        for (char *p = (str + strlen(str)) - 3; p > str; p -= 3)
        {
            memmove(p + 1, p, strlen(p) + 1);
            *p = ',';
        }
        while (strlen(str) < ds)
        {
            memmove(str + 1, str, strlen(str) + 1);
            *str = ' ';
        }
        gfx->println(str);
    }
}

int32_t testFillScreen()
{
    uint32_t start = micros_start();
    // Shortened this tedious test!
    gfx->fillScreen(WHITE);
    gfx->fillScreen(RED);
    gfx->fillScreen(GREEN);
    gfx->fillScreen(BLUE);
    gfx->fillScreen(BLACK);

    return micros() - start;
}

int32_t testText()
{
    uint32_t start = micros_start();
    gfx->setCursor(0, 0);

    gfx->setTextSize(1);
    gfx->setTextColor(WHITE, BLACK);
    gfx->println(F("Hello World!"));

    gfx->setTextSize(2);
    gfx->setTextColor(gfx->color565(0xff, 0x00, 0x00));
    gfx->print(F("RED "));
    gfx->setTextColor(gfx->color565(0x00, 0xff, 0x00));
    gfx->print(F("GREEN "));
    gfx->setTextColor(gfx->color565(0x00, 0x00, 0xff));
    gfx->println(F("BLUE"));

    gfx->setTextSize(tsa);
    gfx->setTextColor(YELLOW);
    gfx->println(1234.56);

    gfx->setTextColor(WHITE);
    gfx->println((w > 128) ? 0xDEADBEEF : 0xDEADBEE, HEX);

    gfx->setTextColor(CYAN, WHITE);
    gfx->println(F("Groop,"));

    gfx->setTextSize(tsc);
    gfx->setTextColor(MAGENTA, WHITE);
    gfx->println(F("I implore thee,"));

    gfx->setTextSize(1);
    gfx->setTextColor(NAVY, WHITE);
    gfx->println(F("my foonting turlingdromes."));

    gfx->setTextColor(DARKGREEN, WHITE);
    gfx->println(F("And hooptiously drangle me"));

    gfx->setTextColor(DARKCYAN, WHITE);
    gfx->println(F("with crinkly bindlewurdles,"));

    gfx->setTextColor(MAROON, WHITE);
    gfx->println(F("Or I will rend thee"));

    gfx->setTextColor(PURPLE, WHITE);
    gfx->println(F("in the gobberwartsb"));

    gfx->setTextColor(OLIVE, WHITE);
    gfx->println(F("with my blurglecruncheon,"));

    gfx->setTextColor(DARKGREY, WHITE);
    gfx->println(F("see if I don't!"));

    gfx->setTextSize(2);
    gfx->setTextColor(RED);
    gfx->println(F("Size 2"));

    gfx->setTextSize(3);
    gfx->setTextColor(ORANGE);
    gfx->println(F("Size 3"));

    gfx->setTextSize(4);
    gfx->setTextColor(YELLOW);
    gfx->println(F("Size 4"));

    gfx->setTextSize(5);
    gfx->setTextColor(GREENYELLOW);
    gfx->println(F("Size 5"));

    gfx->setTextSize(6);
    gfx->setTextColor(GREEN);
    gfx->println(F("Size 6"));

    gfx->setTextSize(7);
    gfx->setTextColor(BLUE);
    gfx->println(F("Size 7"));

    gfx->setTextSize(8);
    gfx->setTextColor(PURPLE);
    gfx->println(F("Size 8"));

    gfx->setTextSize(9);
    gfx->setTextColor(PINK);
    gfx->println(F("Size 9"));

    return micros() - start;
}

int32_t testPixels()
{
    uint32_t start = micros_start();

    for (int16_t y = 0; y < h; y++)
    {
        for (int16_t x = 0; x < w; x++)
        {
            gfx->drawPixel(x, y, gfx->color565(x << 3, y << 3, x * y));
        }
#ifdef ESP8266
        yield(); // avoid long run triggered ESP8266 WDT restart
#endif
    }

    return micros() - start;
}

int32_t testLines()
{
    uint32_t start;
    int32_t x1, y1, x2, y2;

    start = micros_start();

    x1 = y1 = 0;
    y2 = h - 1;
    for (x2 = 0; x2 < w; x2 += 6)
    {
        gfx->drawLine(x1, y1, x2, y2, BLUE);
    }
#ifdef ESP8266
    yield(); // avoid long run triggered ESP8266 WDT restart
#endif

    x2 = w - 1;
    for (y2 = 0; y2 < h; y2 += 6)
    {
        gfx->drawLine(x1, y1, x2, y2, BLUE);
    }
#ifdef ESP8266
    yield(); // avoid long run triggered ESP8266 WDT restart
#endif

    x1 = w - 1;
    y1 = 0;
    y2 = h - 1;
    for (x2 = 0; x2 < w; x2 += 6)
    {
        gfx->drawLine(x1, y1, x2, y2, BLUE);
    }
#ifdef ESP8266
    yield(); // avoid long run triggered ESP8266 WDT restart
#endif

    x2 = 0;
    for (y2 = 0; y2 < h; y2 += 6)
    {
        gfx->drawLine(x1, y1, x2, y2, BLUE);
    }
#ifdef ESP8266
    yield(); // avoid long run triggered ESP8266 WDT restart
#endif

    x1 = 0;
    y1 = h - 1;
    y2 = 0;
    for (x2 = 0; x2 < w; x2 += 6)
    {
        gfx->drawLine(x1, y1, x2, y2, BLUE);
    }
#ifdef ESP8266
    yield(); // avoid long run triggered ESP8266 WDT restart
#endif

    x2 = w - 1;
    for (y2 = 0; y2 < h; y2 += 6)
    {
        gfx->drawLine(x1, y1, x2, y2, BLUE);
    }
#ifdef ESP8266
    yield(); // avoid long run triggered ESP8266 WDT restart
#endif

    x1 = w - 1;
    y1 = h - 1;
    y2 = 0;
    for (x2 = 0; x2 < w; x2 += 6)
    {
        gfx->drawLine(x1, y1, x2, y2, BLUE);
    }
#ifdef ESP8266
    yield(); // avoid long run triggered ESP8266 WDT restart
#endif

    x2 = 0;
    for (y2 = 0; y2 < h; y2 += 6)
    {
        gfx->drawLine(x1, y1, x2, y2, BLUE);
    }
#ifdef ESP8266
    yield(); // avoid long run triggered ESP8266 WDT restart
#endif

    return micros() - start;
}

int32_t testFastLines()
{
    uint32_t start;
    int32_t x, y;

    start = micros_start();

    for (y = 0; y < h; y += 5)
    {
        gfx->drawFastHLine(0, y, w, RED);
    }
    for (x = 0; x < w; x += 5)
    {
        gfx->drawFastVLine(x, 0, h, BLUE);
    }

    return micros() - start;
}

int32_t testFilledRects()
{
    uint32_t start;
    int32_t i, i2;

    start = micros_start();

    for (i = n; i > 0; i -= 6)
    {
        i2 = i / 2;

        gfx->fillRect(cx - i2, cy - i2, i, i, gfx->color565(i, i, 0));
    }

    return micros() - start;
}

int32_t testRects()
{
    uint32_t start;
    int32_t i, i2;

    start = micros_start();
    for (i = 2; i < n; i += 6)
    {
        i2 = i / 2;
        gfx->drawRect(cx - i2, cy - i2, i, i, GREEN);
    }

    return micros() - start;
}

int32_t testFilledCircles(uint8_t radius)
{
    uint32_t start;
    int32_t x, y, r2 = radius * 2;

    start = micros_start();

    for (x = radius; x < w; x += r2)
    {
        for (y = radius; y < h; y += r2)
        {
            gfx->fillCircle(x, y, radius, MAGENTA);
        }
    }

    return micros() - start;
}

int32_t testCircles(uint8_t radius)
{
    uint32_t start;
    int32_t x, y, r2 = radius * 2;
    int32_t w1 = w + radius;
    int32_t h1 = h + radius;

    // Screen is not cleared for this one -- this is
    // intentional and does not affect the reported time.
    start = micros_start();

    for (x = 0; x < w1; x += r2)
    {
        for (y = 0; y < h1; y += r2)
        {
            gfx->drawCircle(x, y, radius, WHITE);
        }
    }

    return micros() - start;
}

int32_t testFillArcs()
{
    int16_t i, r = 360 / cn;
    uint32_t start = micros_start();

    for (i = 6; i < cn; i += 6)
    {
        gfx->fillArc(cx1, cy1, i, i - 3, 0, i * r, RED);
    }

    return micros() - start;
}

int32_t testArcs()
{
    int16_t i, r = 360 / cn;
    uint32_t start = micros_start();

    for (i = 6; i < cn; i += 6)
    {
        gfx->drawArc(cx1, cy1, i, i - 3, 0, i * r, WHITE);
    }

    return micros() - start;
}

int32_t testFilledTriangles()
{
    uint32_t start;
    int32_t i;

    start = micros_start();

    for (i = cn1; i > 10; i -= 5)
    {
        gfx->fillTriangle(cx1, cy1 - i, cx1 - i, cy1 + i, cx1 + i, cy1 + i,
                          gfx->color565(0, i, i));
    }

    return micros() - start;
}

int32_t testTriangles()
{
    uint32_t start;
    int32_t i;

    start = micros_start();

    for (i = 0; i < cn; i += 5)
    {
        gfx->drawTriangle(
            cx1, cy1 - i,     // peak
            cx1 - i, cy1 + i, // bottom left
            cx1 + i, cy1 + i, // bottom right
            gfx->color565(0, 0, i));
    }

    return micros() - start;
}

int32_t testFilledRoundRects()
{
    uint32_t start;
    int32_t i, i2;

    start = micros_start();

    for (i = n1; i > 20; i -= 6)
    {
        i2 = i / 2;
        gfx->fillRoundRect(cx - i2, cy - i2, i, i, i / 8, gfx->color565(0, i, 0));
    }

    return micros() - start;
}

int32_t testRoundRects()
{
    uint32_t start;
    int32_t i, i2;

    start = micros_start();

    for (i = 20; i < n1; i += 6)
    {
        i2 = i / 2;
        gfx->drawRoundRect(cx - i2, cy - i2, i, i, i / 8, gfx->color565(i, 0, 0));
    }

    return micros() - start;
}

/***************************************************
  Original sketch text:

  This is an example sketch for the Adafruit 2.2" SPI display.
  This library works with the Adafruit 2.2" TFT Breakout w/SD card
  ----> http://www.adafruit.com/products/1480

  Check out the links above for our tutorials and wiring diagrams
  These displays use SPI to communicate, 4 or 5 pins are required to
  interface (RST is optional)
  Adafruit invests time and resources providing this open source code,
  please support Adafruit and open-source hardware by purchasing
  products from Adafruit!

  Written by Limor Fried/Ladyada for Adafruit Industries.
  MIT license, all text above must be included in any redistribution
 ****************************************************/

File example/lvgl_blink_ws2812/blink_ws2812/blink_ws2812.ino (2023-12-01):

#include <lvgl.h>
#include <Arduino_GFX_Library.h>
#include <Wire.h>
#include <ui.h>
#include <Adafruit_NeoPixel.h>

#include "touch.h"

/*Don't forget to set Sketchbook location in File/Preferencesto the path of your UI project (the parent foder of this INO file)*/
#define I2C_SDA_PIN 17
#define I2C_SCL_PIN 18
#define TOUCH_RST -1 // 38
#define TOUCH_IRQ -1 // 0

#define TFT_BL 38
#define BUTTON_PIN 14
#define ENCODER_CLK 13 // CLK
#define ENCODER_DT 10  // DT

#define RX_PIN 44
#define TX_PIN 43

#define WS2812_PIN RX_PIN
#define NUMPIXELS 50
#define DELAYVAL 50
/*Change to your screen resolution*/
static const uint16_t screenWidth = 480;
static const uint16_t screenHeight = 480;

static lv_disp_draw_buf_t draw_buf;
static lv_color_t buf[screenWidth * screenHeight / 10];

Arduino_ESP32RGBPanel *bus = new Arduino_ESP32RGBPanel(
    1 /* CS */, 46 /* SCK */, 0 /* SDA */,
    2 /* DE */, 42 /* VSYNC */, 3 /* HSYNC */, 45 /* PCLK */,
    11 /* R0 */, 15 /* R1 */, 12 /* R2 */, 16 /* R3 */, 21 /* R4 */,
    39 /* G0/P22 */, 7 /* G1/P23 */, 47 /* G2/P24 */, 8 /* G3/P25 */, 48 /* G4/P26 */, 9 /* G5 */,
    4 /* B0 */, 41 /* B1 */, 5 /* B2 */, 40 /* B3 */, 6 /* B4 */
);

// Uncomment for 2.1" round display
Arduino_ST7701_RGBPanel *gfx = new Arduino_ST7701_RGBPanel(
    bus, GFX_NOT_DEFINED /* RST */, 0 /* rotation */,
    false /* IPS */, 480 /* width */, 480 /* height */,
    st7701_type5_init_operations, sizeof(st7701_type5_init_operations),
    true /* BGR */,
    10 /* hsync_front_porch */, 8 /* hsync_pulse_width */, 50 /* hsync_back_porch */,
    10 /* vsync_front_porch */, 8 /* vsync_pulse_width */, 20 /* vsync_back_porch */);

Adafruit_NeoPixel pixels(NUMPIXELS, WS2812_PIN, NEO_GRB + NEO_KHZ800);

uint32_t my_color[8];

int counter = 0;
int State;
int old_State;
int move_flag = 0;

int flush_delay = 500;

void setup()
{
    USBSerial.begin(115200); /* prepare for possible serial debug */

    String LVGL_Arduino = "Hello Arduino! ";
    LVGL_Arduino += String('V') + lv_version_major() + "." + lv_version_minor() + "." + lv_version_patch();

    USBSerial.println(LVGL_Arduino);
    USBSerial.println("I am LVGL_Arduino");

    my_color[0] = pixels.Color(255, 0, 0);
    my_color[1] = pixels.Color(0, 255, 0);
    my_color[2] = pixels.Color(0, 0, 255);
    my_color[3] = pixels.Color(255, 255, 0);
    my_color[4] = pixels.Color(0, 255, 255);
    my_color[5] = pixels.Color(255, 0, 255);
    my_color[6] = pixels.Color(128, 0, 128);
    my_color[7] = pixels.Color(0, 128, 0);

    pin_init();
    gfx->begin();

    lv_init();
    lv_disp_draw_buf_init(&draw_buf, buf, NULL, screenWidth * screenHeight / 10);

    /*Initialize the display*/
    static lv_disp_drv_t disp_drv;
    lv_disp_drv_init(&disp_drv);
    /*Change the following line to your display resolution*/
    disp_drv.hor_res = screenWidth;
    disp_drv.ver_res = screenHeight;
    disp_drv.flush_cb = my_disp_flush;
    disp_drv.draw_buf = &draw_buf;
    lv_disp_drv_register(&disp_drv);

    /*Initialize the (dummy) input device driver*/
    static lv_indev_drv_t indev_drv;
    lv_indev_drv_init(&indev_drv);
    indev_drv.type = LV_INDEV_TYPE_POINTER;
    indev_drv.read_cb = my_touchpad_read;
    lv_indev_drv_register(&indev_drv);

    // encoder
    static lv_indev_drv_t indev_drv2;
    lv_indev_drv_init(&indev_drv2);
    indev_drv2.type = LV_INDEV_TYPE_ENCODER;
    indev_drv2.read_cb = my_encoder_read;
    lv_indev_t *encoder_indev = lv_indev_drv_register(&indev_drv2);

    ui_init();

    lv_group_t *g = lv_group_create();
    lv_group_add_obj(g, ui_Arc1);
    lv_indev_set_group(encoder_indev, g);

    USBSerial.println("Setup done");

    pixels.begin();
    pixels.setBrightness(60);
    pixels.clear();
    pixels.show();

    xTaskCreatePinnedToCore(Task_TFT, "Task_TFT", 20480, NULL, 3, NULL, 0);
    xTaskCreatePinnedToCore(Task_main, "Task_main", 40960, NULL, 3, NULL, 1);
}

void loop()
{
}
//---------------------------------------------------
void Task_TFT(void *pvParameters)
{
    while (1)
    {
        lv_timer_handler();
        vTaskDelay(10);
    }
}

void Task_main(void *pvParameters)
{
    while (1)
    {
        String temp = "Bink Delay:";
        temp = temp + flush_delay;
        lv_label_set_text(ui_Label3, temp.c_str());

        int brightness = lv_arc_get_value(ui_Arc1) * 10;
        pixels.setBrightness(brightness);
        fresh_led();
        vTaskDelay(flush_delay);
    }
}

//--------------------------

void pin_init()
{
    pinMode(TFT_BL, OUTPUT);
    digitalWrite(TFT_BL, HIGH);

    pinMode(ENCODER_CLK, INPUT_PULLUP);
    pinMode(ENCODER_DT, INPUT_PULLUP);
    old_State = digitalRead(ENCODER_CLK);

    attachInterrupt(ENCODER_CLK, encoder_irq, CHANGE);

    Wire.begin(I2C_SDA_PIN, I2C_SCL_PIN);
}

/* Display flushing */
void my_disp_flush(lv_disp_drv_t *disp, const lv_area_t *area, lv_color_t *color_p)
{
    uint32_t w = (area->x2 - area->x1 + 1);
    uint32_t h = (area->y2 - area->y1 + 1);

#if (LV_COLOR_16_SWAP != 0)
    gfx->draw16bitBeRGBBitmap(area->x1, area->y1, (uint16_t *)&color_p->full, w, h);
#else
    gfx->draw16bitRGBBitmap(area->x1, area->y1, (uint16_t *)&color_p->full, w, h);
#endif

    lv_disp_flush_ready(disp);
}

/*Read the touchpad*/
void my_touchpad_read(lv_indev_drv_t *indev_driver, lv_indev_data_t *data)
{
    int touchX = 0, touchY = 0;

    if (read_touch(&touchX, &touchY) == 1)
    {
        data->state = LV_INDEV_STATE_PR;

        data->point.x = (uint16_t)touchX;
        data->point.y = (uint16_t)touchY;
    }
    else
    {
        data->state = LV_INDEV_STATE_REL;
    }
}

void my_encoder_read(lv_indev_drv_t *drv, lv_indev_data_t *data)
{
    if (counter > 0)
    {
        data->state = LV_INDEV_STATE_PRESSED;
        data->key = LV_KEY_RIGHT;
        counter--;
        move_flag = 1;
    }

    else if (counter < 0)
    {
        data->state = LV_INDEV_STATE_PRESSED;
        data->key = LV_KEY_LEFT;
        counter++;
        move_flag = 1;
    }
    else
    {
        data->state = LV_INDEV_STATE_RELEASED;
    }
}

void encoder_irq()
{
    State = digitalRead(ENCODER_CLK);
    if (State != old_State)
    {
        if (digitalRead(ENCODER_DT) == State)
        {
            counter++;
        }
        else
        {
            counter--;
        }
    }
    old_State = State; // the first position was changed
}

void fresh_led()
{

    for (int i = 0; i < NUMPIXELS; i++)
    { // For each pixel...

        // pixels.Color() takes RGB values, from 0,0,0 up to 255,255,255
        // Here we're using a moderately bright green color:
        // pixels.setPixelColor(i, pixels.Color(0, 150, 0));

        pixels.setPixelColor(i, my_color[random(0, 7)]);

        // vTaskDelay(DELAYVAL); // Pause before next pass through loop
    }

    pixels.show(); // Send the updated pixel colors to the hardware.
}

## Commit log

2023-08-24 Add hardware
    [MaTouch ESP32-S3 Rotary IPS Display with Touch 2.1“ ST7701 v1.1.brd, MaTouch ESP32-S3 Rotary IPS Display with Touch 2.1“ ST7701 v1.1.sch]
2023-10-18 Add schematic of PDF

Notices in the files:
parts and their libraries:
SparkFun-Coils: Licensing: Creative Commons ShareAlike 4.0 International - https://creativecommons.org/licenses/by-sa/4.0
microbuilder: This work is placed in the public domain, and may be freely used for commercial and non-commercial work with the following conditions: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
